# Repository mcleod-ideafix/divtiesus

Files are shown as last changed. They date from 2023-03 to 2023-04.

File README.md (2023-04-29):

# DivTIESUS
DivTIESUS is a SD/MMC card interface for the ZX Spectrum. First designed by Mario Pratto as DivMMC, DivTIESUS is an independent design, compatible with the I/O ports and mapper used both in DivIDE and DivMMC, but adding more features.

There is a larger version of DivTIESUS, nicknamed "Pijus Magnificus" edition. This one is the "Tiesus del tó" version, which I have released for the community, so anyone can build his/her own interface.

# Features
- DivMMC compatible interface with 8 KiB of EEPROM and 128 KiB of RAM. Standard utils for EEPROM flashing, as provided by the ESXDOS team, are compatible with DivTIESUS.
- Model autodetection. This means you don't need to put a jumper, or flip a switch to change from using it with a Spectrum 48K and a +3.
- Tested with ZX Spectrum 48K issue 1, 2, 3, 3B, 4A, 4B and 6A. NEC and Hitachi ROM chips. Also tested on Inves Spectrum, Spectrum 128K (both english and spanish versions), +2 grey, +2A, +2B and +3. Also tested on Harlequin 48K. Compatible with TK90X also.
- It uses its own fast clock (25 MHz). It does not need the CPU clock at all.
- Rear expansion port continuation, allowing the user to plug another device. Note that ROMCS and other signals are not filtered.
- NMI button to call file browser in ESXDOS, and handy RESET button. The RESET button is placed so that it won't be accidentally pressed while operating the interface.
- Standard SD card slot (accepts both big SD cards and microSD cards (with adapter).
- A single switch is used to indicate DivTIESUS that the EEPROM can be flashed (JP2 equivalent) and the automapping feature is disabled.
- Visual feedback for SD activity (blue led) and update EEPROM mode (red led).
- ESXDOS shadowing does not collide with all-RAM feature in +2A/B/3 machines. If the system is in all-RAM mode, ESXDOS ROM mapping is disabled.
- Soft +3E feature: DivTIESUS is able to load +3E ROM images from the SD card, install them as the system ROM (using its own RAM), and make them available to the computer, while disabling the automapping feature (needed for ESXDOS but not for +3eDOS). This, effectively, allows the user to operate his/her +2A/B/3 machine as a +2e/3e one, all without having to open the case and exchange ROMs. A new dot command, ".go3e" makes this possible. Such command only works with DivTIESUS.
- Soft ROM feature: the soft +3E feature can also be used to load any 16K, 32K or 64K ROM and make the computer to boot with that ROM (the dot command currently supports only 16K ROMs). This means that ROM images for some util/games available for the Spectrum can be run in their original form. No need to have a +2A/B/3 machine to use them.

# Pictures
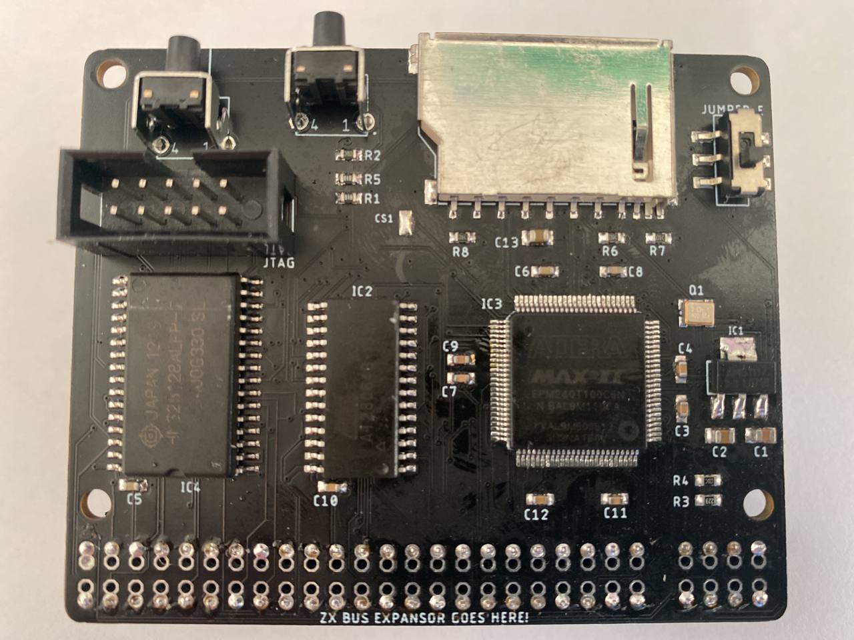
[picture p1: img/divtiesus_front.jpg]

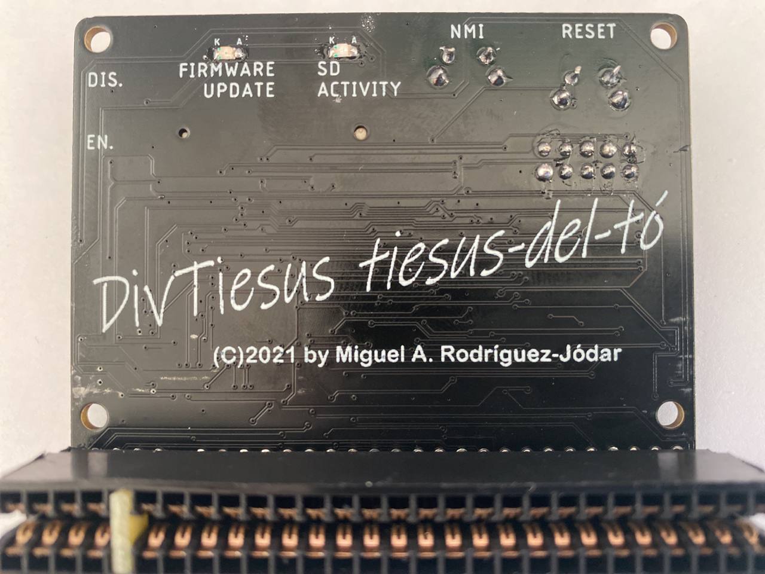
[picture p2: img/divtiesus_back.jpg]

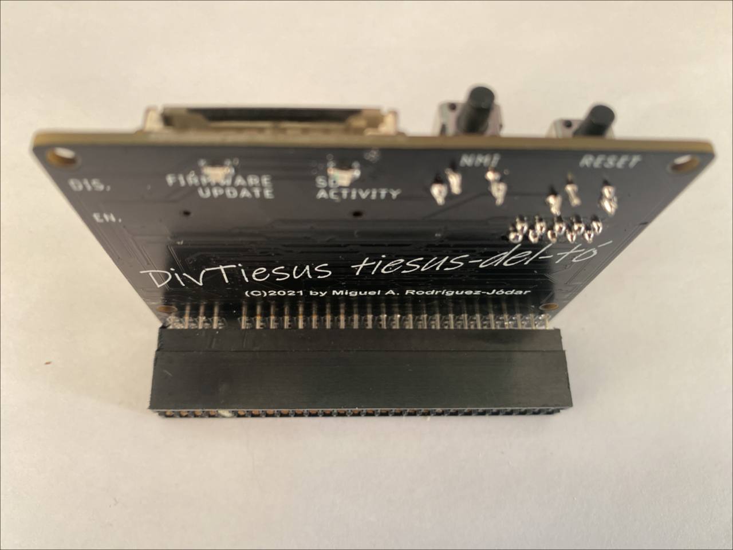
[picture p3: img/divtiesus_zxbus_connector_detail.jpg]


# Schematic, board and layout (top and flipped bottom side)
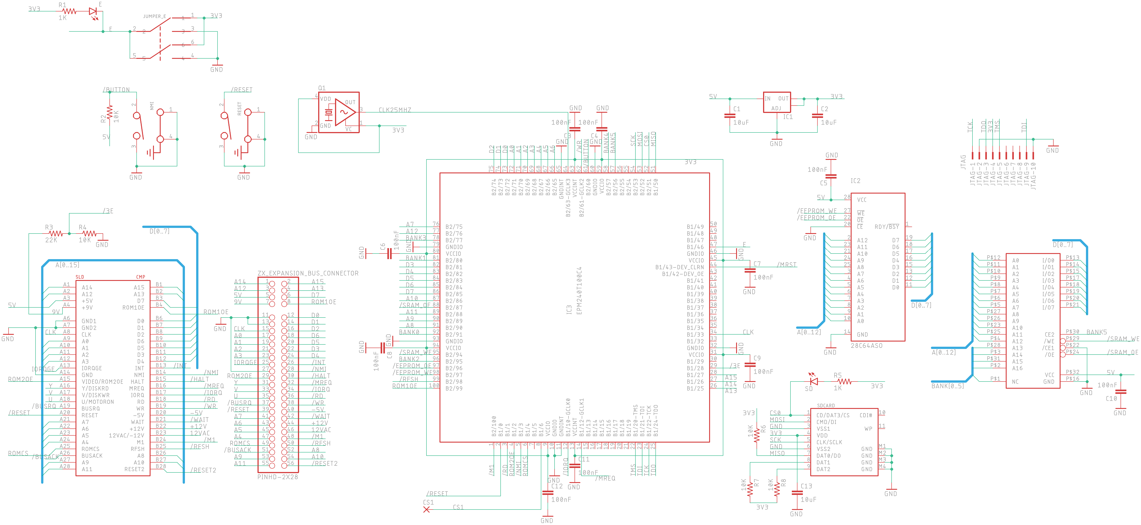
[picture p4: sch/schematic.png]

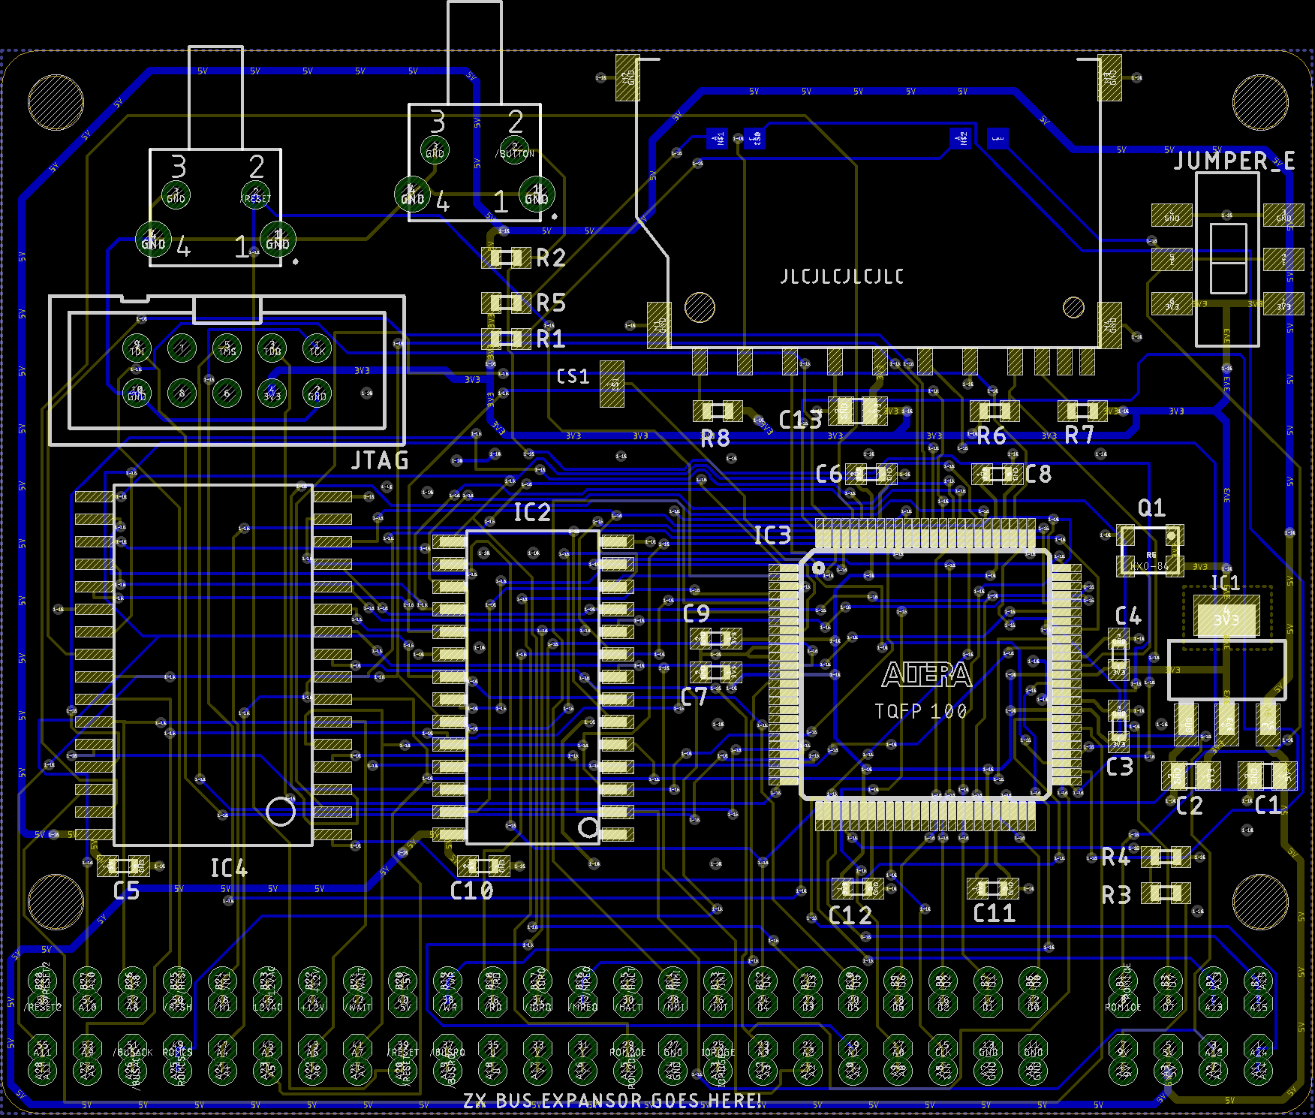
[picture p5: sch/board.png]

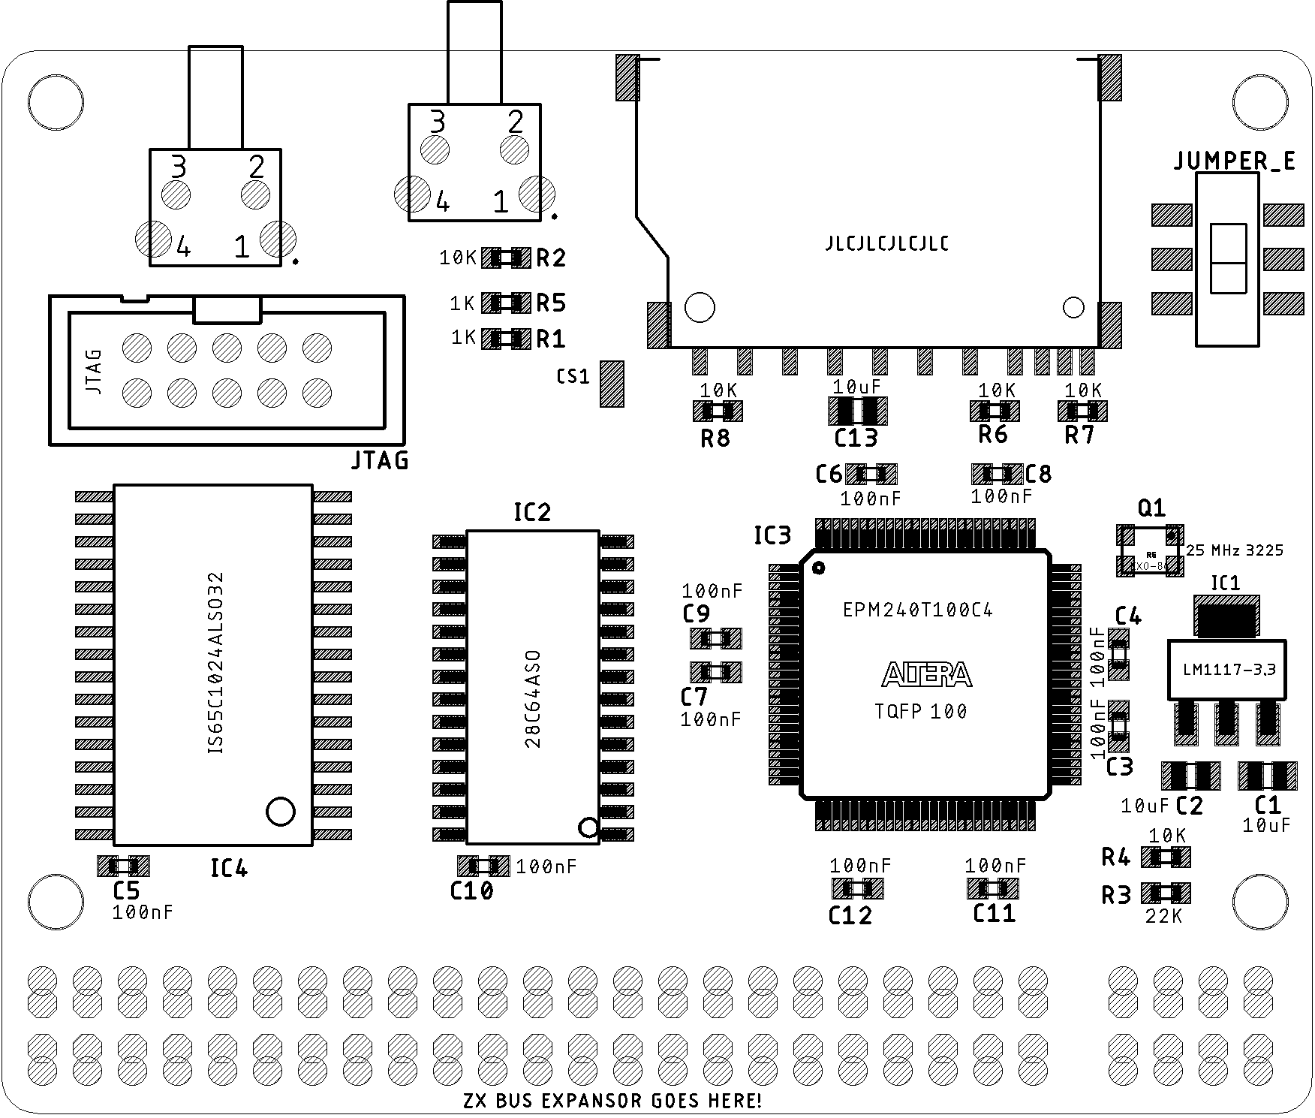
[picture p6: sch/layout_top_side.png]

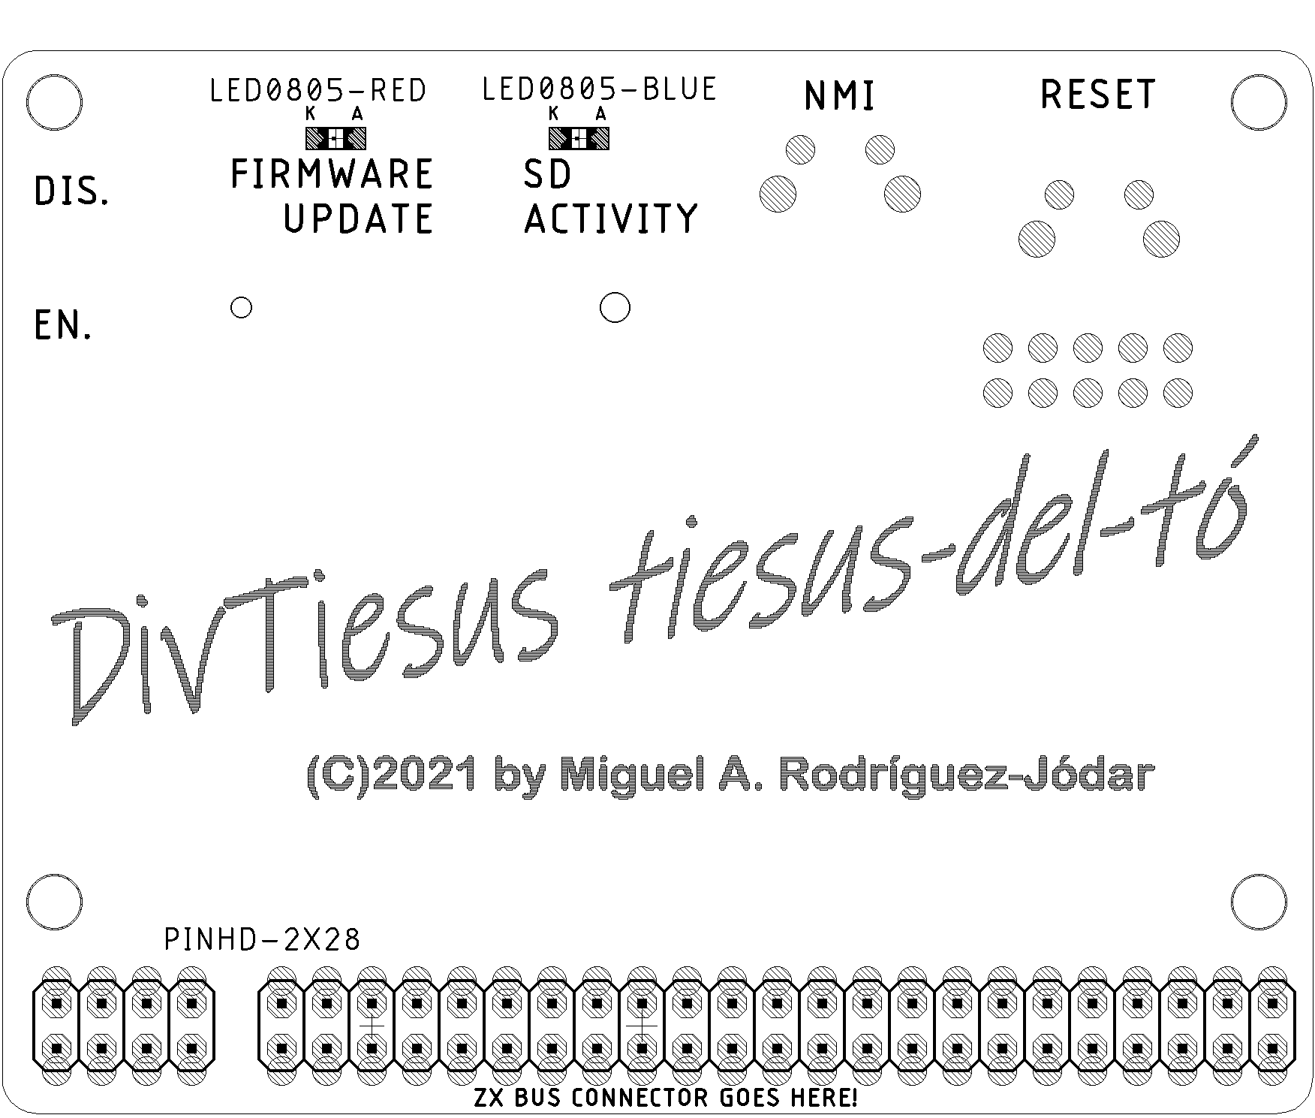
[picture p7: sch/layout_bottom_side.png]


# Build
- First, you need the DivTIESUS PCB. You can order it from JLCPCB using the files in "gerber" directory. They are already tailored for JLCPCB PCB process.
- Second: get the component list. Following is the BOM, with Mouser references to get parts from them, but most of the components are rather standard so you can get it from severla other distributors. Many of them can also be obtained from Aliexpress.

## Bill of materials
|Qty|Value|PCB part|Mouser ref.|
| --- | --- | --- | --- |
|2|WS-TATU-TH 431256058726|NMI, RESET|710-431256058726|
|1|SDCARD SLOT|SDCARD|523-GMC020080HR|
|2|1K|R1, R5|603-RC0603FR-131KL|
|5|10K|R2, R4, R6, R7, R8|603-RC0603FR-1310KL|
|3|10uF|C1, C2, C13|581-0805YC106KAT2A|
|1|22K|R3|603-RC0603FR-1322KL|
|1|25 MHz 3225|Q1|520-3225Q-33-240-BST|
|1|28C64ASO|IC2|556-AT28C64B15SU|
|10|100nF|C3, C4, C5, C6, C7, C8, C9, C10, C11, C12|581-0603YC104J4T4A|
|1|CONECTOR_BUS_TRASERO|U$1|571-5530843-6|
|1|EPM240T100C4|IC3|989-EPM240T100C4|
|1|IS65C1024ALSO32|IC4|727-CY62128ELL45SXIT|
|1|JTAG|JTAG|517-N2510-6002RB|
|1|LED0805-BLUE|SD ACTIVITY|710-150080BS75000|
|1|LED0805-RED|FIRMWARE UPDATE ENABLED|710-150080RS75000|
|1|LM1117-3.3|IC1|511-LD1117S33|
|1|SWITCH_SMD_6PIN|JUMPER_E|4000030382277 (Aliexpress)|

- The oscillator does not need to be 25 MHz. It can be about any value between 14 and 30 MHz (it may even work with values outside these limits -not tested-)
- It is very advisable to use a stencil and solder paste for the soldering process. You don't really need a reflow oven, as parts can be soldered using hot air. There are plenty of Youtube videos covering the matter.
- Start placing passives (resistors, capacitors, going from right to left. Leave the SRAM, EEPROM, SD socket and CPLD for the end (in this order). Don't place thru-hole components yet.
- Reflow the top side using an oven, hot plate or hot air. For two pad parts you can even apply the solder tip a few seconds on each pad to allow reflowing it, while keeping the part in place with a pair of tweezers. Same method can be used with SOT-223 parts (the 3.3V regulator), the SD card slot and the SMD switch.
- Turn the board and put-place-solder the two leds. Be aware of polarity with them. Also be aware that these components are very delicate and won't hold much heat, so try to not to apply too much heat and for too much time. You can see in the PCB that (K)athode and (A)node are marked. If you don't like red and blue, use whichever colours you like (or have available).

## First electrical testing
- Check that there is no shortcircuits at the 5V and 3.3V power rails.
- Check that there is no shorts between adjacent pads at the CPLD chip. You may need a magnifying glass to do that. Shorts between adjacent pins at the SRAM or CPLD are easier to notice (I hope).
- To fix any shorts, paste flux is your very best friend. Use it wisely. To me, AMTECH NC-559 solder flux is the best thing to have around (be aware of imitations in Aliexpress!)

After all this first checks, proceed to build and solder the ZX Spectrum bus connector:

## ZX Spectrum bus connector
- Take the 2x28 pin edge connector and cut about 1-2mm on each side to leave the ends opened, as in the last picture of this section.
- With a pair of tweezers, pull and extract the two metal contacts that are positioned at 5th place, where the index tab will be.
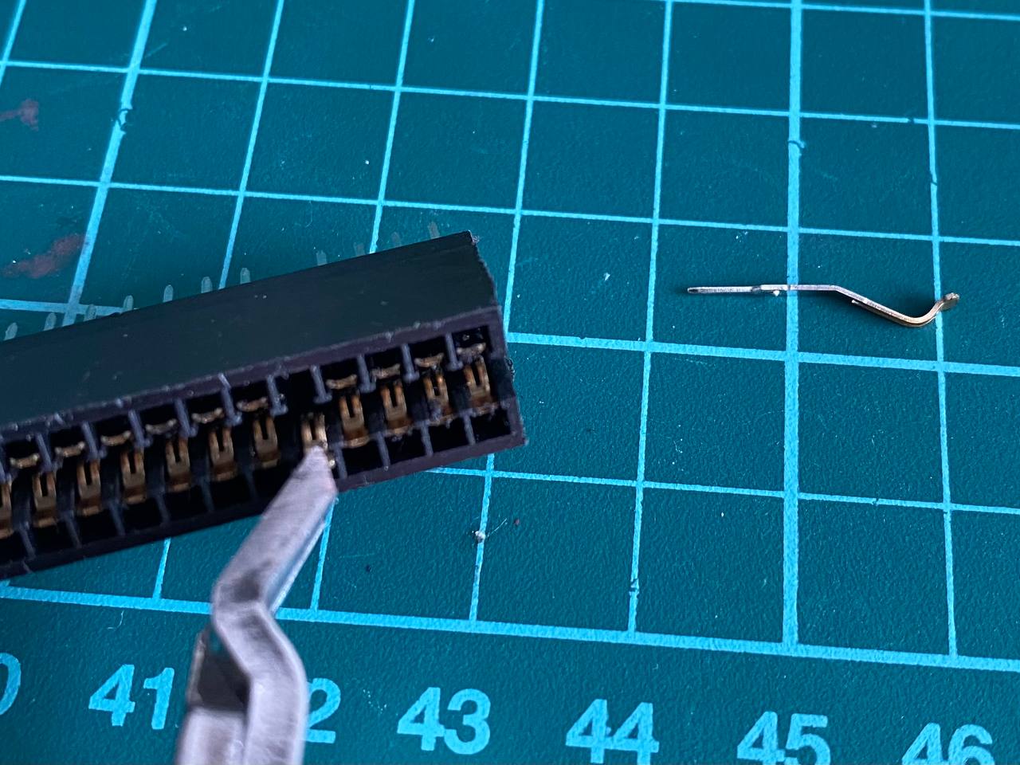
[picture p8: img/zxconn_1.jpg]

- Now take a small piece you can get from a PCB, 1.5mm thick and 7mm tall. This will be the index tab.
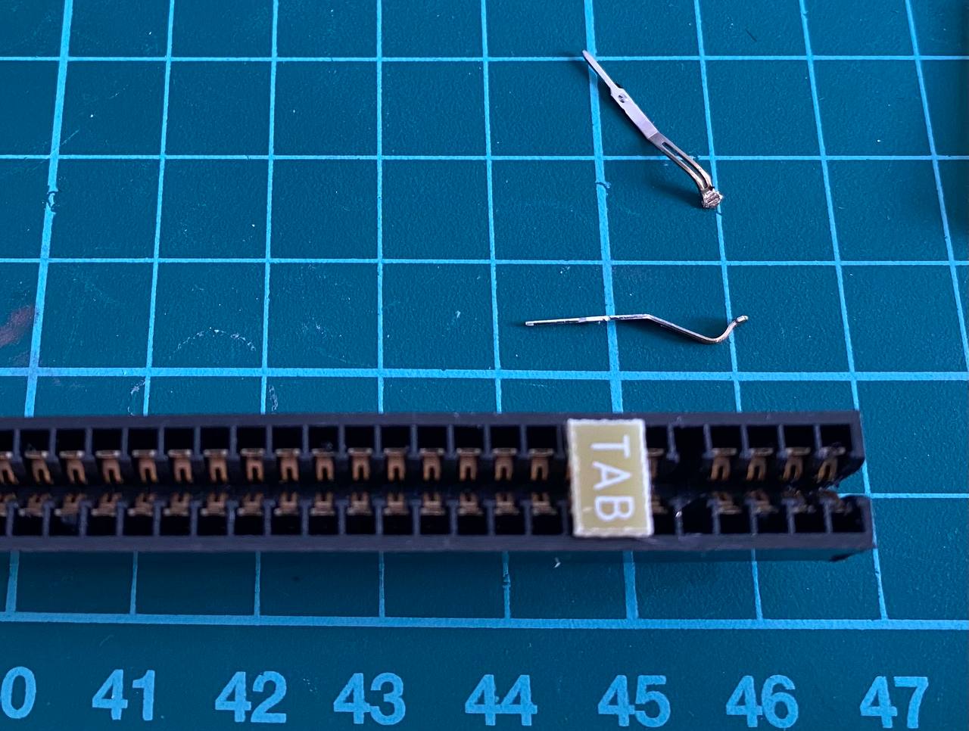
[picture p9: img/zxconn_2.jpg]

- Place the piece in the index hole. Sand it if it's too tall for the hole.
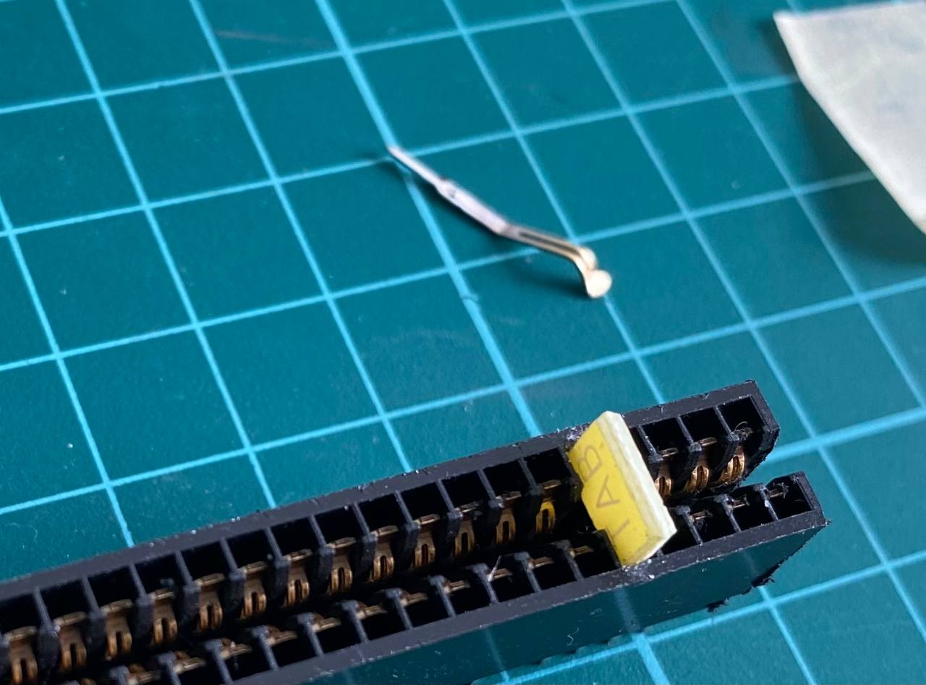
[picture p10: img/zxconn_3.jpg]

- Using a pair of pliers, push it in place. If it's too small for the hole, use some glue to keep it from coming loose.
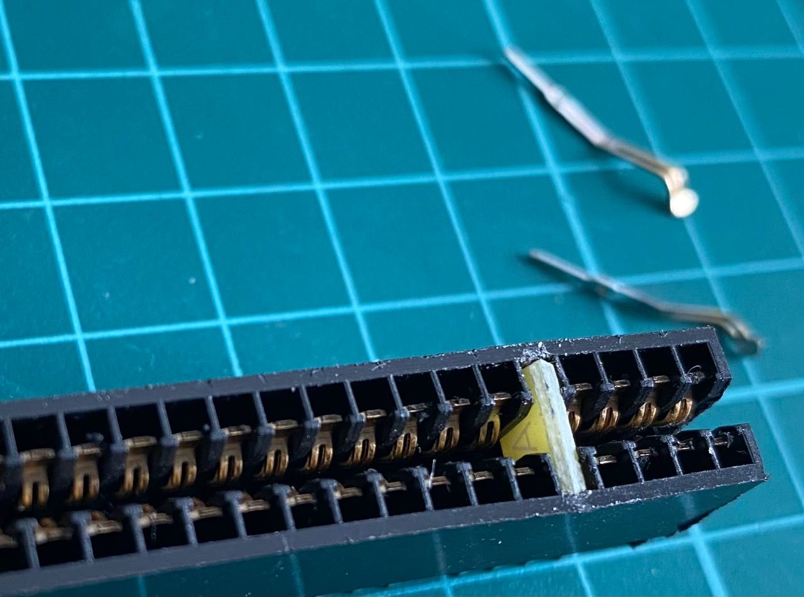
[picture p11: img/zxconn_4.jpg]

Now the edge connector is ready to work as a ZX Spectrum rear bus connector!                                                      
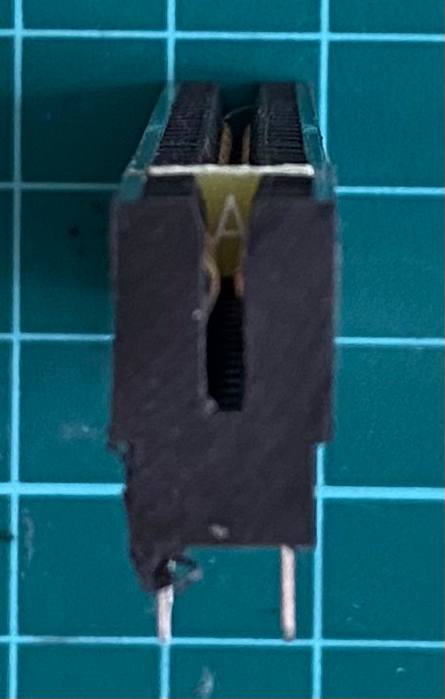
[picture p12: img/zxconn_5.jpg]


# FAQ (in progress)
***Is this the same version as you have already on sale?***
Almost! This version is the basic version, which is also the cheapest one I've made. Although it's the "basic" version, it has plenty of features, not present in any other DivMMC-like interface, atm.

***Can I take this, build or have someone else build some units, sell them and make some profit?***
I'm ok with that. I only ask you two things: do not remove my copyright noptice from the silk screen and any other document present in this repository, and if you make changes, additions, or otherwise improve the board, make those changes public and available for others as well.

***Can I adapt the Verilog code for a Xilinx part, like XC95144XL?***
Yes, but take into account that XC95 CPLDs doesn't have programmmable pull-ups, so you might need to add some 10K resistors to the board.

***Can I use 512K SRAM chips instead of 128K? Will the board recognize and use it at full capacity?***
Yes to both questions.

***I can see a "divmmc_mcleod_nom1.v" file with a version of the DivMMC module that isn't being used. What is that for?***
Glad you asked! It's an experimental DivMMC module that **DOESN'T NEED THE M1 SIGNAL FROM THE Z80**. It's experimental in the way that it works most of the time, but sometimes, not. If you program the CPLD with this version, it will use the RFSH signal instead of M1 to map and unmap the EEPROM, and a slighly sofisticated method to find out if it is in a M1 cycle, or memory read cycle, to inmediately map the EEPROM for TRDOS traps. More on this later.

***What "tiesus-del-tó" means?***
It means "really really broke".

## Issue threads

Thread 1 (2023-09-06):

EPM240T100C5 insteed of EPM240T100C4 ?

vgolovanov, 2023-09-06:
Is it possible to replace EPM240T100C4 by EPM240T100C5 part ?

chuckcaley, 2023-11-16:
Yes it will work fine.

mcleod-ideafix, 2023-11-16:
Oh! didn’t I answer to this email? Yes, both parts will do fine. Also I4 and I5.El 16 nov 2023, a las 21:57, chuckcaley ***@***.***> escribió:
Yes it will work fine.

—Reply to this email directly, view it on GitHub, or unsubscribe.You are receiving this because you are subscribed to this thread.Message ID: ***@***.***>

Closed 2023-11-17.

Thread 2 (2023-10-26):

Programming the board?

barbiani, 2023-10-26:
Hi,

I have just found this nice project of yours.

After the board is assembled, how is the EPROM loaded? Do we use a programmer to load esxdos?

Thank you.

mcleod-ideafix, 2023-10-27:
Hi! To program the EEPROM with ESXDOS you have to get ESXDOS latest version (0.8.9 at the time of this writting), and you will find ESXMMC.TAP . You must load that file using audio to your Spectrum and follow instructions Enviado desde mi iPhoneEl 26 oct 2023, a las 23:55, barbiani ***@***.***> escribió:
Hi,
I have just found this nice project of yours.
After the board is assembled, how is the EPROM loaded? Do we use a programmer to load esxdos?
Thank you.

—Reply to this email directly, view it on GitHub, or unsubscribe.You are receiving this because you are subscribed to this thread.Message ID: ***@***.***>

PicoElements, 2024-04-07:
Hi! I was wondering if i can use a EPM570 in place of the EPM240. Just because i have one spare.. Thanks!

toledi, 2024-07-03:
Greetings from Slovenia

I have just build this awsome PCB and now I get an error when trying to upload firmware.
I have fully working ZX spectrum 48k, load the ESXMMC.TAP via tape player, put the DIVTIESUS switch do DIS position (red led ON), hit any key on spectrum and it gives me the error:
CANNOT FLASH
DIVIDE ERROR
0 OK, 3:8

What am I doing wrong? Please help?
Best Regards, Denis
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

distropia2, 2024-10-07:
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

Hi, late response but just in case you still did not have the answer: that probably means that the eeprom 28c64b is write protected, so you have to use the EPROTECTOR utility from Velesoft to unprotect the eeprom and after a reset you will be able to program it. Read this: https://foro.speccy.org/viewtopic.php?t=1324

Hope it helps!

PicoElements, 2024-11-23:
Hi,
is it possible to preprogram the EEprom with a standard EsxDos  binary?

Thanks,
Stefano

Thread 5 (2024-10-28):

esxsdos.sys loading error

luckrm, 2024-10-28:
HI
Thank you for the project, very nice
I built two boards and both have this issue, exsdos.sys loading error and reset of the Spectrum
I programmed the eeprom with ESXMMC.BIN from esxdos089 with an external programmer and soldered it
then I programmed the Altera chip with tld_divtiesus.pof but I am stocked with esxdos.sys loading error
tried two different sd cards 32 and 16 gb filled with bin and sys dir from exsdos089
What I am doing wrong?
thank you

lotharek1977, 2024-11-09:
99% you have damaged eeprom content. flash it from tape to fix or reprogram. generally i do not flash production units with eprom in socket.

luckrm, 2024-11-09:
thanks lotharek1977, I solved the problem changing the oscillator, it must be active 3,3 volts

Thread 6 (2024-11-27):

ZX Spectrum diagnostics

k2-mirror, 2024-11-27:
Hello McLeod, this project is amazing, but i have a question.
Can i use divtiesus to  diagnose my ZX spectrum like a dandanator does?

Hola McLeod, éste proyecto me parece una maravilla.
Pero tengo una duda, ¿se puede hacer con el divtiesus un diagnóstico del ZX Spectrum como el que se hace con un dandanator?
Gracias!!

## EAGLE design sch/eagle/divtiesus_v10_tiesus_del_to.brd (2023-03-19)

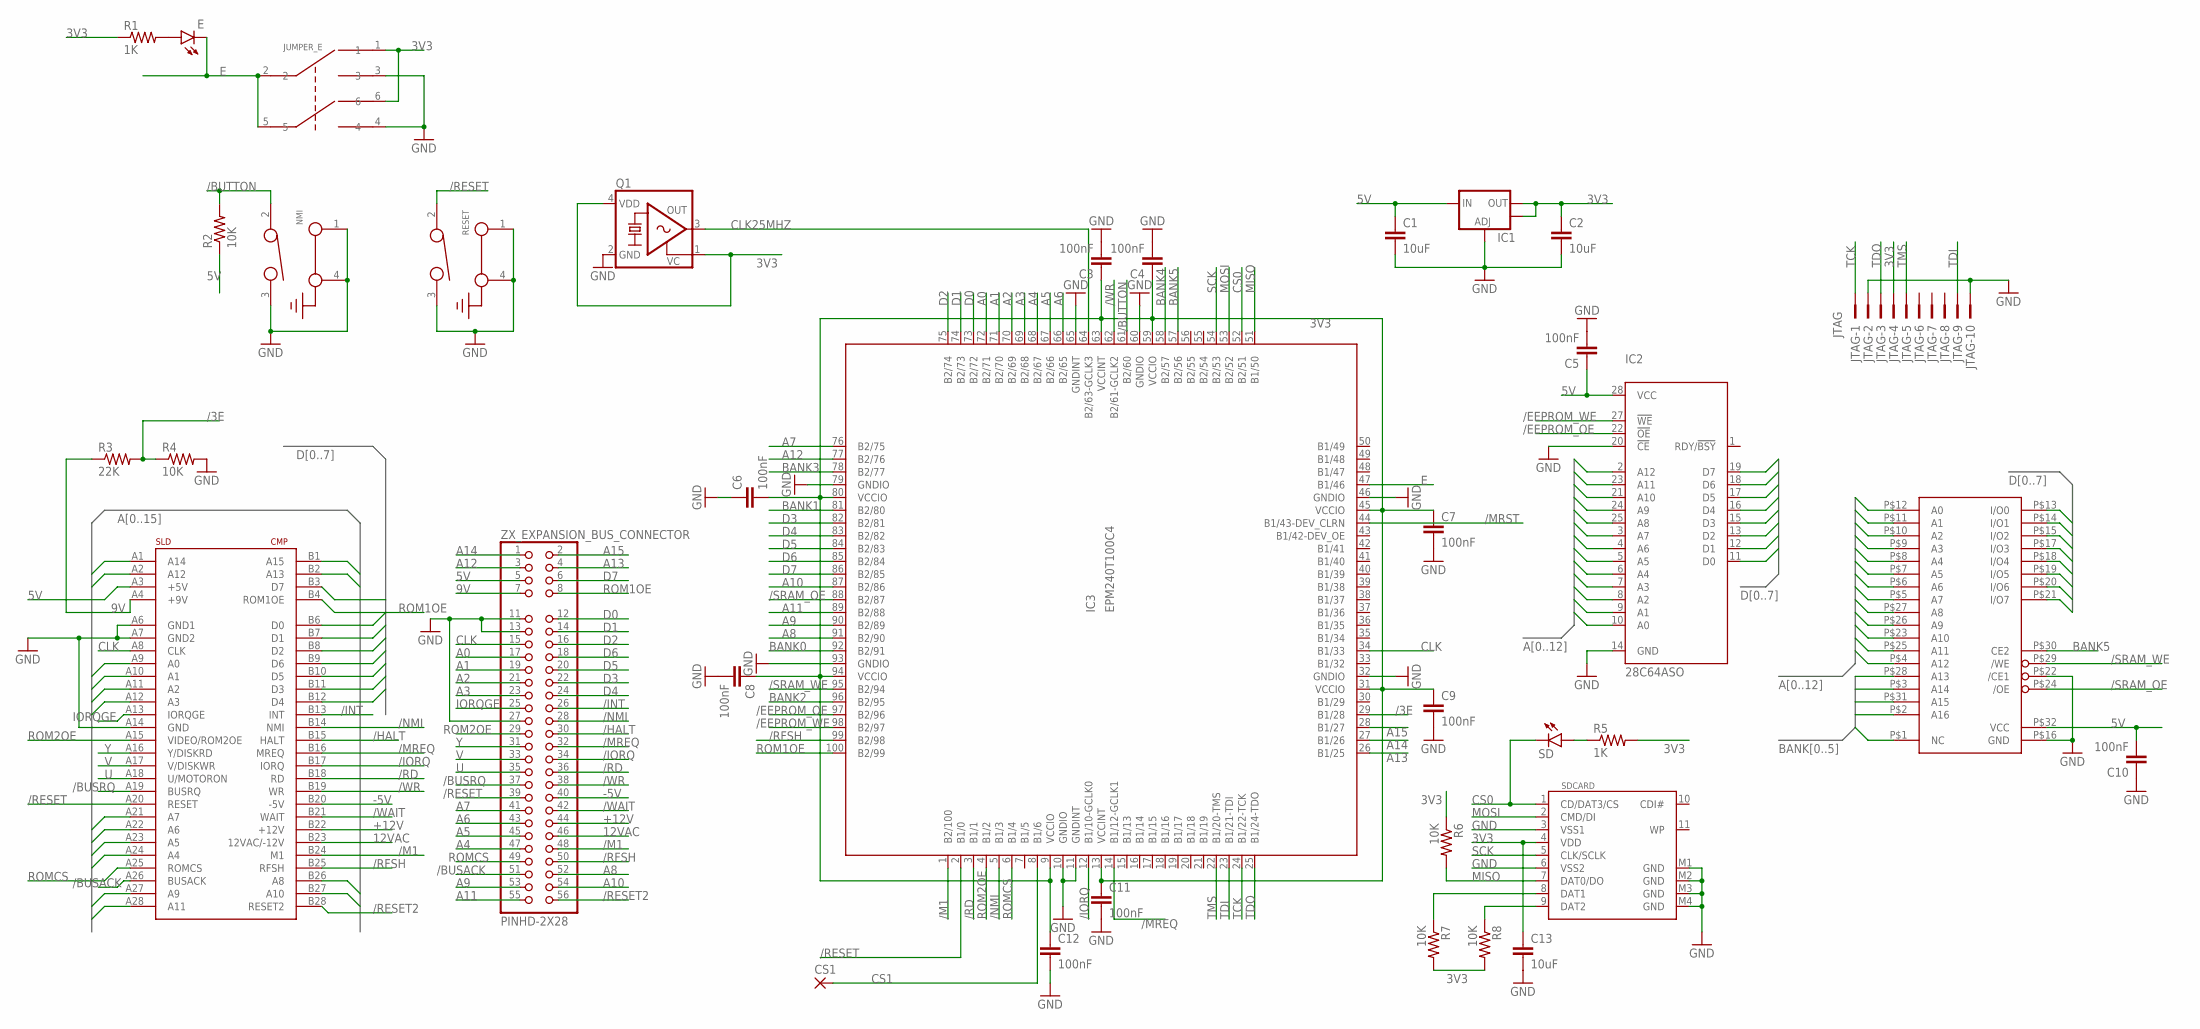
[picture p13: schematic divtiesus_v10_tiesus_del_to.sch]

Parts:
C1, C2, C13: 10uF; C0805
C3, C4, C5, C6, C7, C8, C9, C10, C11, C12: 100nF; C0603K
CS1: SMD2; SMD1,27-2,54
E: LEDCHIPLED_0805; CHIPLED_0805
IC1: V_REG_LM1117SOT223; SOT223
IC2: 28C64ASO; SO28W
IC3: EPM240T100C4; TQFP100
IC4: IS65C1024ALSO32; SO32-545MIL
JTAG: JTAG; PAK100/2500-10
JUMPER_E: SWITCH_SMD_6PIN; SMD-6PIN
NMI: 431256083716
Q1: KXO-VCTCXO-SINE-84; 3.2X2.5_KXO-84-VCTCXO
R1, R5: 1K; R0603
R2, R4, R6, R7, R8: 10K; R0603
R3: 22K; R0603
RESET: 431256083716
SD: LEDCHIPLED_0805; CHIPLED_0805
SDCARD: SDCARD; SDCMF-10915W010
U$1: CONECTOR_BUS_TRASERO; CONECTOR_SIMPLE_CARA
ZX_EXPANSION_BUS_CONNECTOR: PINHD-2X28; 2X28

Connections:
3V3: C2.1, C3.1, C4.1, C6.2, C7.1, C8.1, C9.1, C11.1, C12.1, C13.1, IC1.2 (OUT), IC1.4 (OUT), IC3.9 (VCCIO), IC3.13 (VCCINT), IC3.31 (VCCIO), IC3.45 (VCCIO), IC3.59 (VCCIO), IC3.63 (VCCINT), IC3.80 (VCCIO), IC3.94 (VCCIO), JTAG.4, JUMPER_E.1, JUMPER_E.6, Q1.1 (VC), Q1.4 (VDD), R1.1, R5.2, R6.1, R7.2, R8.2, SDCARD.4 (VDD)
5V: C1.1, C5.1, C10.2, IC1.3 (IN), IC2.28 (VCC), IC4.P$32 (VCC), R2.1, U$1.A3 (+5V), ZX_EXPANSION_BUS_CONNECTOR.5
9V: R3.1, U$1.A4 (+9V), ZX_EXPANSION_BUS_CONNECTOR.7
12VAC: U$1.B23 (12VAC/-12V), ZX_EXPANSION_BUS_CONNECTOR.46
+12V: U$1.B22 (+12V), ZX_EXPANSION_BUS_CONNECTOR.44
-5V: U$1.B20 (-5V), ZX_EXPANSION_BUS_CONNECTOR.40
/3E: IC3.29 (B1/28), R3.2, R4.1
/BUSACK: U$1.A26 (BUSACK), ZX_EXPANSION_BUS_CONNECTOR.51
/BUSRQ: U$1.A19 (BUSRQ), ZX_EXPANSION_BUS_CONNECTOR.37
/BUTTON: IC3.61 (B2/60), NMI.2, R2.2
/EEPROM_OE: IC2.22 (!OE), IC3.97 (B2/96)
/EEPROM_WE: IC2.27 (!WE), IC3.98 (B2/97)
/HALT: U$1.B15 (HALT), ZX_EXPANSION_BUS_CONNECTOR.30
/INT: U$1.B13 (INT), ZX_EXPANSION_BUS_CONNECTOR.26
/IORQ: IC3.12 (B1/10-GCLK0), U$1.B17 (IORQ), ZX_EXPANSION_BUS_CONNECTOR.34
/M1: IC3.1 (B2/100), U$1.B24 (M1), ZX_EXPANSION_BUS_CONNECTOR.48
/MREQ: IC3.14 (B1/12-GCLK1), U$1.B16 (MREQ), ZX_EXPANSION_BUS_CONNECTOR.32
/MRST: IC3.44 (B1/43-DEV_CLRN)
/NMI: IC3.5 (B1/3), U$1.B14 (NMI), ZX_EXPANSION_BUS_CONNECTOR.28
/RD: IC3.3 (B1/1), U$1.B18 (RD), ZX_EXPANSION_BUS_CONNECTOR.36
/RESET: IC3.2 (B1/0), RESET.2, U$1.A20 (RESET), ZX_EXPANSION_BUS_CONNECTOR.39
/RESET2: U$1.B28 (RESET2), ZX_EXPANSION_BUS_CONNECTOR.56
/RFSH: IC3.99 (B2/98), U$1.B25 (RFSH), ZX_EXPANSION_BUS_CONNECTOR.50
/SRAM_OE: IC3.88 (B2/87), IC4.P$24 (/OE)
/SRAM_WE: IC3.95 (B2/94), IC4.P$29 (/WE)
/WAIT: U$1.B21 (WAIT), ZX_EXPANSION_BUS_CONNECTOR.42
/WR: IC3.62 (B2/61-GCLK2), U$1.B19 (WR), ZX_EXPANSION_BUS_CONNECTOR.38
A0: IC2.10 (A0), IC3.72 (B2/71), IC4.P$12 (A0), U$1.A9 (A0), ZX_EXPANSION_BUS_CONNECTOR.17
A1: IC2.9 (A1), IC3.71 (B2/70), IC4.P$11 (A1), U$1.A10 (A1), ZX_EXPANSION_BUS_CONNECTOR.19
A2: IC2.8 (A2), IC3.70 (B2/69), IC4.P$10 (A2), U$1.A11 (A2), ZX_EXPANSION_BUS_CONNECTOR.21
A3: IC2.7 (A3), IC3.69 (B2/68), IC4.P$9 (A3), U$1.A12 (A3), ZX_EXPANSION_BUS_CONNECTOR.23
A4: IC2.6 (A4), IC3.68 (B2/67), IC4.P$8 (A4), U$1.A24 (A4), ZX_EXPANSION_BUS_CONNECTOR.47
A5: IC2.5 (A5), IC3.67 (B2/66), IC4.P$7 (A5), U$1.A23 (A5), ZX_EXPANSION_BUS_CONNECTOR.45
A6: IC2.4 (A6), IC3.66 (B2/65), IC4.P$6 (A6), U$1.A22 (A6), ZX_EXPANSION_BUS_CONNECTOR.43
A7: IC2.3 (A7), IC3.76 (B2/75), IC4.P$5 (A7), U$1.A21 (A7), ZX_EXPANSION_BUS_CONNECTOR.41
A8: IC2.25 (A8), IC3.91 (B2/90), IC4.P$27 (A8), U$1.B26 (A8), ZX_EXPANSION_BUS_CONNECTOR.52
A9: IC2.24 (A9), IC3.90 (B2/89), IC4.P$26 (A9), U$1.A27 (A9), ZX_EXPANSION_BUS_CONNECTOR.53
A10: IC2.21 (A10), IC3.87 (B2/86), IC4.P$23 (A10), U$1.B27 (A10), ZX_EXPANSION_BUS_CONNECTOR.54
A11: IC2.23 (A11), IC3.89 (B2/88), IC4.P$25 (A11), U$1.A28 (A11), ZX_EXPANSION_BUS_CONNECTOR.55
A12: IC2.2 (A12), IC3.77 (B2/76), IC4.P$4 (A12), U$1.A2 (A12), ZX_EXPANSION_BUS_CONNECTOR.3
A13: IC3.26 (B1/25), U$1.B2 (A13), ZX_EXPANSION_BUS_CONNECTOR.4
A14: IC3.27 (B1/26), U$1.A1 (A14), ZX_EXPANSION_BUS_CONNECTOR.1
A15: IC3.28 (B1/27), U$1.B1 (A15), ZX_EXPANSION_BUS_CONNECTOR.2
BANK0: IC3.92 (B2/91), IC4.P$28 (A13)
BANK1: IC3.81 (B2/80), IC4.P$3 (A14)
BANK2: IC3.96 (B2/95), IC4.P$31 (A15)
BANK3: IC3.78 (B2/77), IC4.P$2 (A16)
BANK4: IC3.58 (B2/57), IC4.P$1 (NC)
BANK5: IC3.57 (B2/56), IC4.P$30 (CE2)
CLK: IC3.34 (B1/33), U$1.A8 (CLK), ZX_EXPANSION_BUS_CONNECTOR.15
CLK25MHZ: IC3.64 (B2/63-GCLK3), Q1.3 (OUT)
CS0: IC3.52 (B2/51), SD.C, SDCARD.1 (CD/DAT3/CS)
CS1: CS1.1, IC3.8 (B1/6)
D0: IC2.11 (D0), IC3.73 (B2/72), IC4.P$13 (I/O0), U$1.B6 (D0), ZX_EXPANSION_BUS_CONNECTOR.12
D1: IC2.12 (D1), IC3.74 (B2/73), IC4.P$14 (I/O1), U$1.B7 (D1), ZX_EXPANSION_BUS_CONNECTOR.14
D2: IC2.13 (D2), IC3.75 (B2/74), IC4.P$15 (I/O2), U$1.B8 (D2), ZX_EXPANSION_BUS_CONNECTOR.16
D3: IC2.15 (D3), IC3.82 (B2/81), IC4.P$17 (I/O3), U$1.B11 (D3), ZX_EXPANSION_BUS_CONNECTOR.22
D4: IC2.16 (D4), IC3.83 (B2/82), IC4.P$18 (I/O4), U$1.B12 (D4), ZX_EXPANSION_BUS_CONNECTOR.24
D5: IC2.17 (D5), IC3.84 (B2/83), IC4.P$19 (I/O5), U$1.B10 (D5), ZX_EXPANSION_BUS_CONNECTOR.20
D6: IC2.18 (D6), IC3.85 (B2/84), IC4.P$20 (I/O6), U$1.B9 (D6), ZX_EXPANSION_BUS_CONNECTOR.18
D7: IC2.19 (D7), IC3.86 (B2/85), IC4.P$21 (I/O7), U$1.B3 (D7), ZX_EXPANSION_BUS_CONNECTOR.6
E: E.C, IC3.47 (B1/46), JUMPER_E.2, JUMPER_E.5
GND: C1.2, C2.2, C3.2, C4.2, C5.2, C6.1, C7.2, C8.2, C9.2, C10.1, C11.2, C12.2, C13.2, IC1.1 (ADJ), IC2.14 (GND), IC2.20 (!CE), IC3.10 (GNDIO), IC3.11 (GNDINT), IC3.32 (GNDIO), IC3.46 (GNDIO), IC3.60 (GNDIO), IC3.65 (GNDINT), IC3.79 (GNDIO), IC3.93 (GNDIO), IC4.P$16 (GND), IC4.P$22 (/CE1), JTAG.2, JTAG.10, JUMPER_E.3, JUMPER_E.4, NMI.1 (GND1), NMI.3, NMI.4 (GND), Q1.2 (GND), R4.2, RESET.1 (GND1), RESET.3, RESET.4 (GND), SDCARD.3 (VSS1), SDCARD.6 (VSS2), SDCARD.M1 (GND), SDCARD.M2 (GND), SDCARD.M3 (GND), SDCARD.M4 (GND), U$1.A6 (GND1), U$1.A7 (GND2), U$1.A14 (GND), ZX_EXPANSION_BUS_CONNECTOR.11, ZX_EXPANSION_BUS_CONNECTOR.13, ZX_EXPANSION_BUS_CONNECTOR.27
IORQGE: U$1.A13 (IORQGE), ZX_EXPANSION_BUS_CONNECTOR.25
MISO: IC3.51 (B1/50), R6.2, SDCARD.7 (DAT0/DO)
MOSI: IC3.53 (B2/52), SDCARD.2 (CMD/DI)
unnamed: R5.1, SD.A
unnamed: E.A, R1.2
unnamed: R7.1, SDCARD.8 (DAT1)
unnamed: R8.1, SDCARD.9 (DAT2)
ROM1OE: IC3.100 (B2/99), U$1.B4 (ROM1OE), ZX_EXPANSION_BUS_CONNECTOR.8
ROM2OE: IC3.4 (B1/2), U$1.A15 (VIDEO/ROM2OE), ZX_EXPANSION_BUS_CONNECTOR.29
ROMCS: IC3.6 (B1/4), U$1.A25 (ROMCS), ZX_EXPANSION_BUS_CONNECTOR.49
SCK: IC3.54 (B2/53), SDCARD.5 (CLK/SCLK)
TCK: IC3.24 (B1/22-TCK), JTAG.1
TDI: IC3.23 (B1/21-TDI), JTAG.9
TDO: IC3.25 (B1/24-TDO), JTAG.3
TMS: IC3.22 (B1/20-TMS), JTAG.5
U: U$1.A18 (U/MOTORON), ZX_EXPANSION_BUS_CONNECTOR.35
V: U$1.A17 (V/DISKWR), ZX_EXPANSION_BUS_CONNECTOR.33
Y: U$1.A16 (Y/DISKRD), ZX_EXPANSION_BUS_CONNECTOR.31

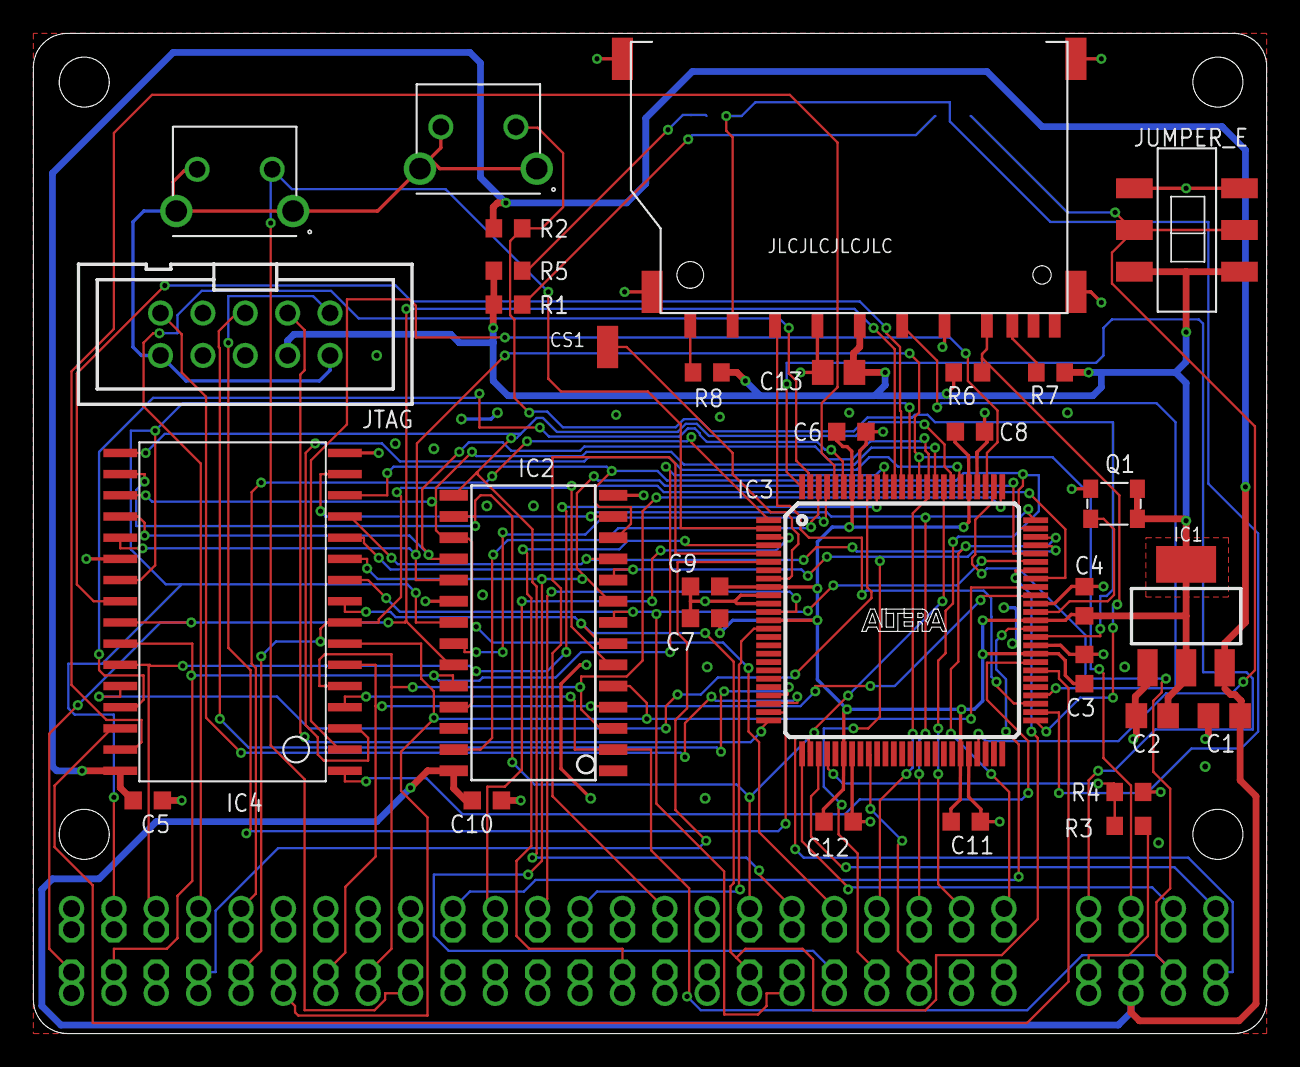
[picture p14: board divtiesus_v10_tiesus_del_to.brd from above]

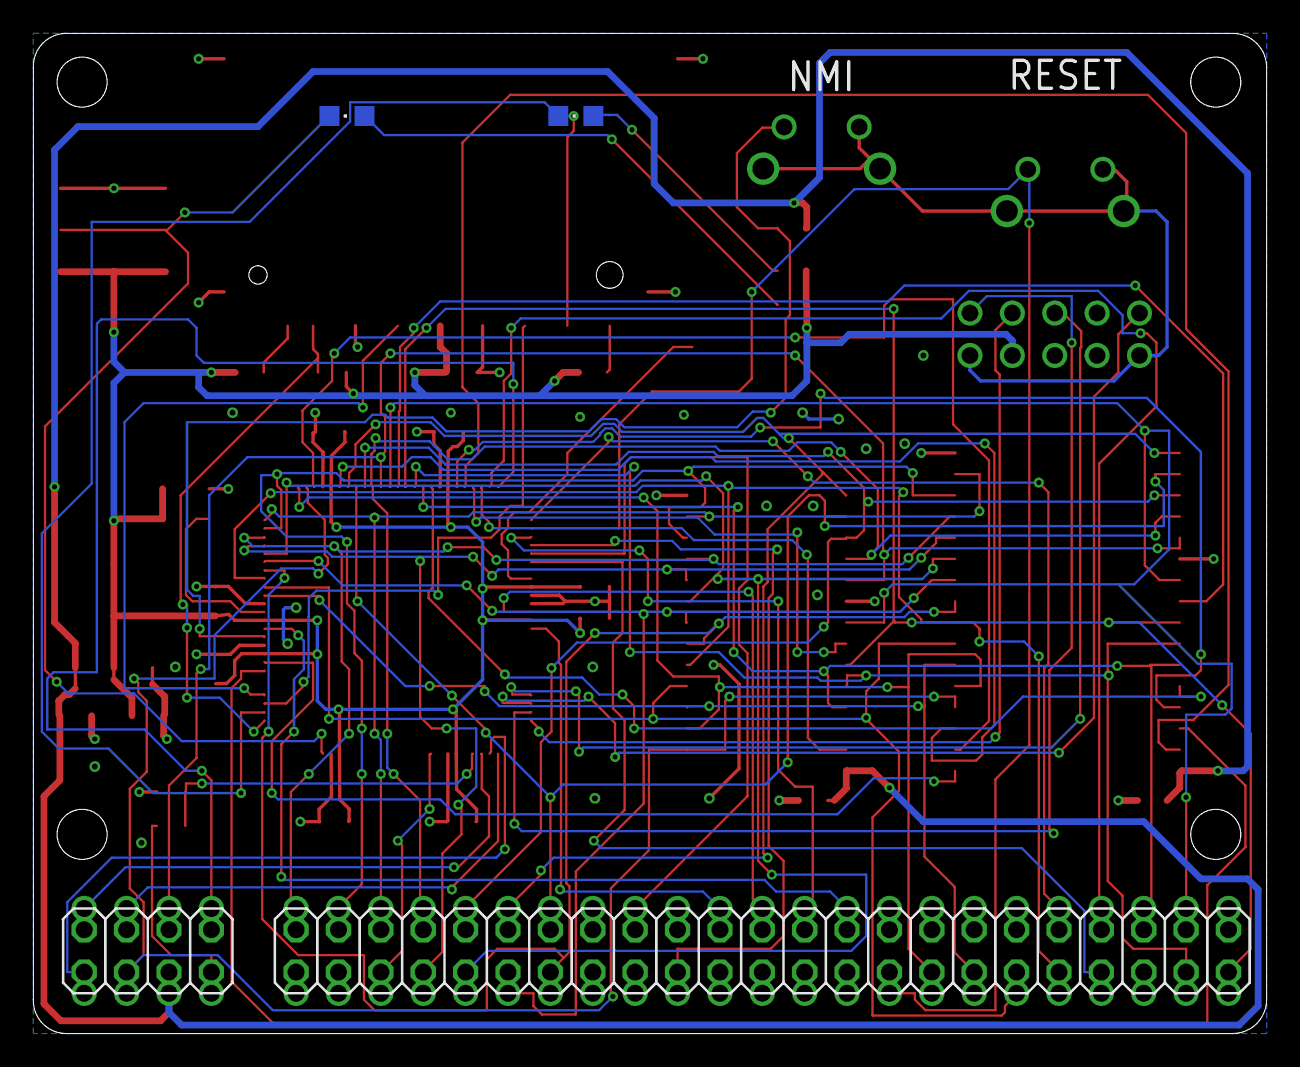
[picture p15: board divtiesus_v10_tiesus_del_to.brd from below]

Board: 2 copper layers, 73.9 x 59.9 mm, 36 parts (4 on the bottom side), 80 nets.

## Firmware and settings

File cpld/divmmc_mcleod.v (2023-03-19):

/*
 * This file is part of the DivTIESUS project
 * Copyright (c) 2021 Miguel Angel Rodriguez Jodar.
 * 
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
 * You should have received a copy of the GNU General Public License 
 * along with this program. If not, see <http://www.gnu.org/licenses/>.
 */

`timescale 1ns / 1ps
`default_nettype none

module divmmc_mcleod (
  // Interface with CPU
  input wire clk,
  input wire rst_n,
  input wire enable_autopage,  // jumper E = 1 (closed). = 0 (open)  
  input wire [15:0] a,
  inout tri [7:0] d,
  input wire mreq_n,
  input wire iorq_n,
  input wire rd_n,
  input wire wr_n,
  input wire m1_n,
  input wire nmi_button_n,  // Button push connects to GND
  output wire nmi_to_cpu_n, // Actual NMI signal to CPU
  // Spectrum ROM shadowing
  input wire inrom48k,  
  output reg zxromcs,   // 1 to disable ZX ROM.
  // DivMMC onboard memory control
  output reg eeprom_cs,
  output reg eeprom_we_n,
  output reg sram_cs,
  output reg sram_write_n,
  output reg [5:0] sram_hiaddr,  // up to 512KB of SRAM can be addressed
  // SPI interface
  output wire sd_cs0_n,
  output wire sd_cs1_n,
  output wire sd_sclk,
  output wire sd_mosi,
  input wire sd_miso  
  );

  localparam
    DIVMMC_CTRL = 8'hE3;

  // DIVMMC control register
  reg mapram_mode = 1'b0;
  reg conmem = 1'b0;
  reg [5:0] divmmc_sram_page = 6'b000000;
  wire iorq_wr = iorq_n | wr_n;
  always @(posedge iorq_wr or negedge rst_n) begin
    if (rst_n == 1'b0) begin
      conmem <= 1'b0;
      divmmc_sram_page <= 6'b000000;
    end
    else if (a[7:0]==DIVMMC_CTRL) begin
      conmem <= d[7];
      mapram_mode <= mapram_mode | d[6];
      divmmc_sram_page <= d[5:0];
    end
  end

  // DIVMMC automapper
  reg divmmc_is_autopaged = 1'b1;
  reg divmmc_autopage_status_after_m1 = 1'b1;
  always @(negedge mreq_n or negedge rst_n) begin
    if (rst_n == 1'b0) begin
      divmmc_is_autopaged <= 1'b1;
      divmmc_autopage_status_after_m1 <= 1'b1;
    end
    else begin
      if (m1_n == 1'b0) begin
        if (a==16'h0000 || inrom48k && (a==16'h0008 || a==16'h0038 || a==16'h0066 || a==16'h04C6 || a==16'h0562 )) begin  // Deferred automapping (maps at the next CPU clock cycle)
          divmmc_autopage_status_after_m1 <= 1'b1;
        end
        else if (a[15:8]==8'h3D && inrom48k) begin  // Non deferred automapping (Current CPU clock cycle)
          divmmc_is_autopaged <= 1'b1;
          divmmc_autopage_status_after_m1 <= 1'b1;
        end
        else if (a[15:3]==13'b0001111111111) begin  // Deferred automapping deactivation
          divmmc_autopage_status_after_m1 <= 1'b0;
        end
      end
      else
        divmmc_is_autopaged <= divmmc_autopage_status_after_m1;      
    end
  end

  // Signal NMI only when DivMMC memory is not paged. This prevents signal bouncing
  assign nmi_to_cpu_n = (nmi_button_n == 1'b0 && divmmc_is_autopaged == 1'b0)? 1'b0 : 1'b1;
  
  // EEPROM, ROMCS and SRAM control and address lines
  always @* begin
    eeprom_cs = 1'b0;
    sram_cs = 1'b0;
    sram_hiaddr = {~divmmc_sram_page[5:4],divmmc_sram_page[3:0]};
    sram_write_n = 1'b1;
    eeprom_we_n = 1'b1;

    if (conmem == 1'b1 || divmmc_is_autopaged == 1'b1 && (enable_autopage == 1'b1 || mapram_mode == 1'b1))
      zxromcs = 1'b1;
    else
      zxromcs = 1'b0;
   
    if (mreq_n == 1'b0 && a[15:14] == 2'b00 /*&& (rd_n == 1'b0 || wr_n == 1'b0)*/ ) begin
   
    //So, when CONMEM is set, there is:
    //0000-1fffh - EEPROM/EPROM/NOTHING(if empty socket), and this area is
    //	   flash-writable if EPROM jumper is open.
    //2000-3fffh - 8k bank, selected by BANK 0..1 bits, always writable.
    if (conmem == 1'b1) begin
      if (a[13] == 1'b0) begin
        if (rd_n == 1'b0) 
          eeprom_cs = 1'b1;
        if (enable_autopage == 1'b0)
          eeprom_we_n = wr_n;
      end  
      else begin
        if (rd_n == 1'b0)
          sram_cs = 1'b1;
        sram_write_n = wr_n;
        sram_hiaddr = {~divmmc_sram_page[5:4],divmmc_sram_page[3:0]};
      end
    end
    
    //When MAPRAM is set, but CONMEM is zero, and entrypoint was reached:
    //0000-1fffh - Bank No.3, read-only
    //2000-3fffh - 8k bank, selected by BANK 0..1. If it's different from Bank No.3,
    //	   it's writable.
    else if (mapram_mode == 1'b1 && conmem == 1'b0 && divmmc_is_autopaged == 1'b1) begin
      if (a[13] == 1'b0) begin
        if (rd_n == 1'b0) begin
          sram_cs = 1'b1;
          sram_hiaddr = 6'b110011;
          sram_write_n = 1'b1;
        end
      end
      else begin
        if (rd_n == 1'b0)
          sram_cs = 1'b1;
        sram_hiaddr = {~divmmc_sram_page[5:4],divmmc_sram_page[3:0]};
        if (divmmc_sram_page != 6'd3) begin
          sram_write_n = wr_n;
        end
        else begin
          sram_write_n = 1'b1;
        end
      end
    end
   
    //When MAPRAM is zero, CONMEM is zero, EPROM jumper is closed and entrypoint was
    //reached:
    //0000-1fffh - EEPROM/EPROM/NOTHING(if empty socket, so open jumper in this case),
    //	   read-only.
    //2000-3fffh - 8k bank, selected by BANK 0..1, always writable.
    else if (enable_autopage == 1'b1 && mapram_mode == 1'b0 && conmem == 1'b0 && divmmc_is_autopaged == 1'b1) begin
      if (a[13] == 1'b0) begin
        if (rd_n == 1'b0)
          eeprom_cs = 1'b1;
      end
      else begin
        if (rd_n == 1'b0)
          sram_cs = 1'b1;
        sram_write_n = wr_n;
        sram_hiaddr = {~divmmc_sram_page[5:4],divmmc_sram_page[3:0]};
      end
    end
    
    //Otherwise, there's normal speccy memory layout. No modified ROM, no shit.  
    else begin
      eeprom_cs = 1'b0;
      sram_cs = 1'b0;
      sram_write_n = 1'b1;
    end
   
    end // del IF que nos dice si estamos accediendo a los primeros 16KB
  end // del always

  sd_card_control sd (
    .clk(clk),
    .rst_n(rst_n),
    .a(a[7:0]),
    .iorq_n(iorq_n),
    .rd_n(rd_n),
    .wr_n(wr_n),
    .d(d),
    
    .sd_cs0_n(sd_cs0_n),
    .sd_cs1_n(sd_cs1_n),
    .sd_sclk(sd_sclk),
    .sd_mosi(sd_mosi),
    .sd_miso(sd_miso)
    );

endmodule
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

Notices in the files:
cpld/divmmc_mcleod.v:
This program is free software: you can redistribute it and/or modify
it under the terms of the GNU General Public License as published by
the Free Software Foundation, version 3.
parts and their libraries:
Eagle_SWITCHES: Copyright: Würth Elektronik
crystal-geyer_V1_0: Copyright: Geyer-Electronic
